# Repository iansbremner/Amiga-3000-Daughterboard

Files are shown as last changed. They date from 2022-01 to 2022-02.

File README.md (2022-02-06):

# Amiga-3000-Daughterboard
This is a recreation of the Rev 9 Daughterboard for the Amiga 3000
This is a 4 Layer board with signal on the upper and lower layers and a Power and Ground Plane.

When fabbing the board you will probably be asked if you want to remove the solder mask on the area for the Edge Connectors. It is fine to say Yes to this.

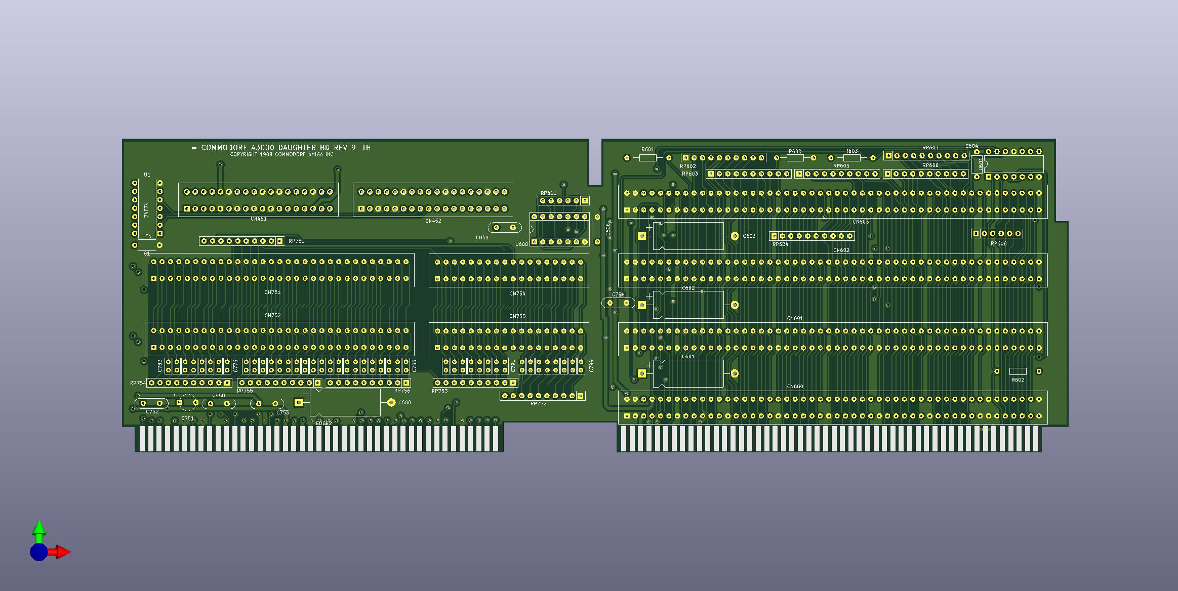
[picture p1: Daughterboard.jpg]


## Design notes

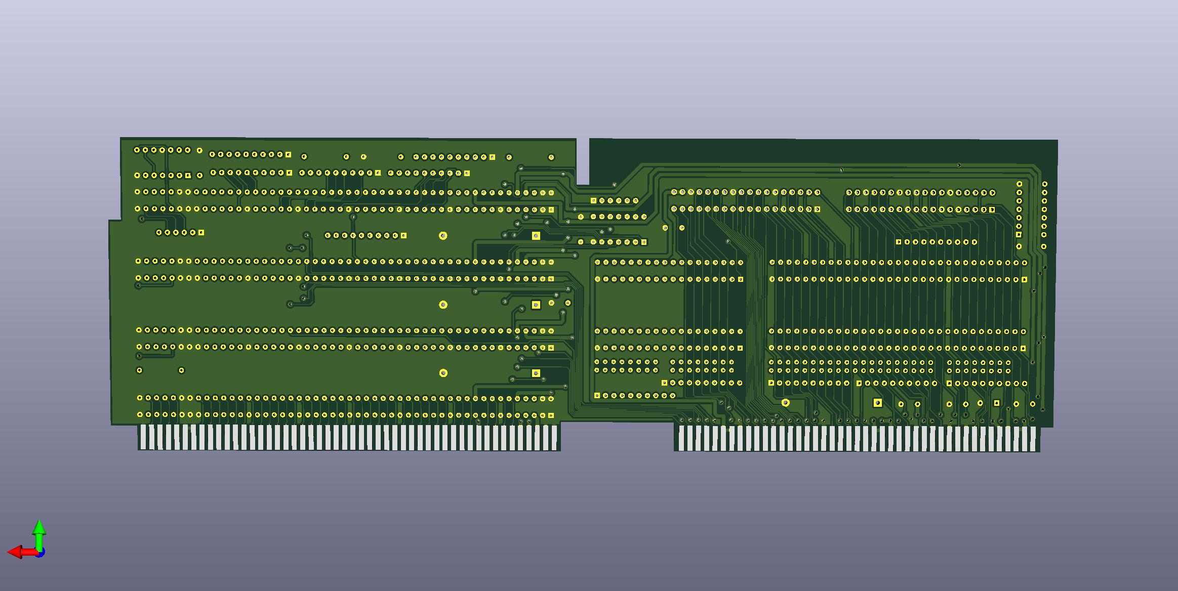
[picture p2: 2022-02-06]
Daughterboard_back.jpg

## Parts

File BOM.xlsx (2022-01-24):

Id | Designator | Package | Quantity | Designation | Part Number | URL | Unit Price | Total Cost
1 | CN752,CN751 | Standard Card Edge Connectors 100 VRT 062DP | 2 | ISA 8 Bit Connector | 6-5530843-5 | https://www.mouser.co.uk/ProductDetail/TE-Connectivity/6-5530843-5?qs=X1mjqRbeMc4evMKvgkFEjA%3D%3D | £3.18 | £6.36
2 | C751 | CP_Radial_D8.0mm_P5.00mm | 1 | 22uF 16V | ECA-1CEN220 | https://www.mouser.co.uk/ProductDetail/Panasonic/ECA-1CEN220 | £0.27 | £0.27
3 | CN755,CN754 | Standard Card Edge Connectors 36 VRT 036DP | 2 | ISA 16 Bit Extended Connector | 2-5530843-7 | https://www.mouser.co.uk/ProductDetail/TE-Connectivity/2-5530843-7?qs=D%2FjeFm%2FW2iQ%2FxNvh55mqEQ%3D%3D | £2.14 | £4.28
4 | RP752,RP753,RP754,RP755,RP756 | R_Array_SIP10 | 5 | 1K | 4610M-101-102LF | https://www.mouser.co.uk/ProductDetail/Bourns/4610M-101-102LF?qs=1EuqX6V5ZrfAKLDENGAusw%3D%3D | £0.47 | £2.34
5 | C458,C752,C753,C754,C849 | C_Disc_D7.0mm_W2.5mm_P5.00mm | 5 | 0.22uF | A224K20X7RF5UAAP | https://www.mouser.co.uk/ProductDetail/Vishay-BC-Components/A224K20X7RF5UAAP?qs=DPoM0jnrROXGL5u3LT1z6Q%3D%3D | £0.42 | £2.10
6 | CN451,CN452 | Standard Card Edge Connectors 36 Position | 2 | Video Slot | 2-5530843-7 | https://www.mouser.co.uk/ProductDetail/TE-Connectivity/2-5530843-7?qs=D%2FjeFm%2FW2iQ%2FxNvh55mqEQ%3D%3D | £2.14 | £4.28
7 | CN602,CN603,CN601,CN600 | Standard Card Edge Connectors CONN SEC II 100POS 100C/L | 4 | Zorro-III | 2-5530843-2 | https://www.mouser.co.uk/ProductDetail/TE-Connectivity-AMP/2-5530843-2 | £6.41 | £25.64
8 | R601,R603 | Resistor | 2 | 470 | SFR2500004700JA500 | https://www.mouser.co.uk/ProductDetail/Vishay-BC-Components/SFR2500004700JA500 | £0.10 | £0.20
9 | C602,C603,C601,C600 | CP_Axial_L21.0mm_D8.0mm_P28.00mm_Horizontal | 4 | 220uF 16V | MAL203135221E3 | https://www.mouser.co.uk/ProductDetail/Vishay-BC-Components/MAL203135221E3?qs=4T%252B5yYZyZYdCTfsAS92uLQ%3D%3D | £1.48 | £5.92
10 | R602,R600 | Resistor | 2 | 1K | MRS16000C1001FC100 | https://www.mouser.co.uk/ProductDetail/Vishay-BC-Components/MRS16000C1001FC100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 | £0.25 | £0.50
12 | U1,U601U600 | DIP-14_W7.62mm_Socket | 3 | DIP Socket | 110-43-314-41-001000 | https://www.mouser.co.uk/ProductDetail/Mill-Max/110-43-314-41-001000?qs=YW4OkVwgsvIOJfZQG89gzQ%3D%3D | £1.11 | £3.33
13 | C784,C785,C788,C786,C787,C789,C790,C793,C794,C792,C795,C756,C757,C758,C759,C760,C761,C762,C763,C764,C765,C766,C767,C768,C769,C770,C771,C772,C773,C774,C775,C776,C777,C778,C779,C780,C781,C782,C783,C791,C796,C797,C798,C799 | C_Rect_L4.6mm_W2.0mm_P2.50mm_MKS02_FKP02 | 44 | 1000pF | A102K15X7RF5UAAP | https://www.mouser.co.uk/ProductDetail/Vishay-BC-Components/A102K15X7RF5UAAP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 | £0.26 | £11.44
15 | RP608 | R_Array_SIP6 | 1 | 220/330 | 4606X-104-221/331L | https://www.mouser.co.uk/ProductDetail/Bourns/4606X-104-221-331L?qs=LaphGdK53R62nJP%252Bgwdp0w%3D%3D | £0.57 | £0.57
16 | RP603,RP602,RP604,RP605,RP606,RP607 | R_Array_SIP10 | 6 | 220/330 | 4610X-104-221/331LF | https://www.mouser.co.uk/ProductDetail/Bourns/4606X-104-221-331L?qs=LaphGdK53R62nJP%252Bgwdp0w%3D%3D | £0.51 | £3.04
18 | C1,C604,C606 | C_Axial_L5.1mm_D3.1mm_P7.50mm_Horizontal | 3 | 0.1uF | A104K15X7RH5UAAP |  | £0.42 | £1.26
19 | RP611 | R_Array_SIP6 | 1 | 1K | 4606M-101-102LF | https://www.mouser.co.uk/ProductDetail/Bourns/4606M-101-102LF?qs=5DXzRwmrLHFQqRAYa1Gabg%3D%3D | £0.51 | £0.51
20 | RP751 | R_Array_SIP10 | 1 | 4.7k | 4610H-101-472LF | https://www.mouser.co.uk/ProductDetail/Bourns/4610H-101-472LF?qs=QW4jRO6c0NMeQaO%252BEgHUiw%3D%3D | £0.55 | £0.55
21 | U600 | DIP-14_W7.62mm | 1 | 74HCT32 | CD74HCT32EE4 | https://www.mouser.co.uk/ProductDetail/Texas-Instruments/CD74HCT32EE4?qs=xFfolx0DHx2nbN4wbr6qGA%3D%3D | £0.56 | £0.56
22 | U601 | DIP-14_W7.62mm | 1 | 7407 | SN7407N | https://www.mouser.co.uk/ProductDetail/Texas-Instruments/SN7407N?qs=sGAEpiMZZMv0NwlthflBi6R2CPM2cSOQ | £0.91 | £0.91
23 | U1 | DIP-14_W7.62mm | 1 | 74F74 | SN74F74N | https://www.mouser.co.uk/ProductDetail/Texas-Instruments/SN74F74N?qs=AMJt07B76usrBxFudkVwtw%3D%3D | £0.51 | £0.51
 |  |  |  |  |  |  |  | £74.58

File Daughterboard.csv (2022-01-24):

Id | Designator | Package | Quantity | Designation | Supplier and ref
1 | CN752,CN751 | ISA 8 Bit | 2 | ISA_8_Bit
2 | C751 | CP_Radial_D8.0mm_P5.00mm | 1 | 22uF 16V
3 | CN755,CN754 | ISA 16 Bit | 2 | ISA_16_Bit_Extended
4 | RP752,RP753,RP754,RP755,RP756 | R_Array_SIP10 | 5 | 1K
5 | C458,C752,C753,C754,C849 | C_Disc_D7.0mm_W2.5mm_P5.00mm | 5 | 0.22uF
6 | CN451,CN452 | Video Slot | 2 | Video_Slot
7 | CN602,CN603,CN601,CN600 | Zorro-III | 4 | Zorro-III
8 | R601,R603 | Resistor | 2 | 470
9 | C602,C603,C601,C600 | CP_Axial_L21.0mm_D8.0mm_P28.00mm_Horizontal | 4 | 220uF 16V
10 | R602,R600 | Resistor | 2 | 1K
11 | EDGE1 | Edge2 | 1 | Edge1
12 | U600 | DIP-14_W7.62mm_Socket | 1 | 74HCT32
13 | C784,C785,C788,C786,C787,C789,C790,C793,C794,C792,C795,C756,C757,C758,C759,C760,C761,C762,C763,C764,C765,C766,C767,C768,C769,C770,C771,C772,C773,C774,C775,C776,C777,C778,C779,C780,C781,C782,C783,C791,C796,C797,C798,C799 | C_Rect_L4.6mm_W2.0mm_P2.50mm_MKS02_FKP02 | 44 | 1000pF
14 | U601 | DIP-14_W7.62mm | 1 | 7407
15 | RP608 | R_Array_SIP6 | 1 | 220/330
16 | RP603,RP602,RP604,RP605,RP606,RP607 | R_Array_SIP10 | 6 | 220/330
17 | EDGE2 | Edge1 | 1 | Edge2
18 | C1,C604,C606 | C_Axial_L5.1mm_D3.1mm_P7.50mm_Horizontal | 3 | 0.1uF
19 | RP611 | R_Array_SIP6 | 1 | 1K
20 | RP751 | R_Array_SIP10 | 1 | 4.7k
21 | U1 | DIP-14_W7.62mm | 1 | 74F74

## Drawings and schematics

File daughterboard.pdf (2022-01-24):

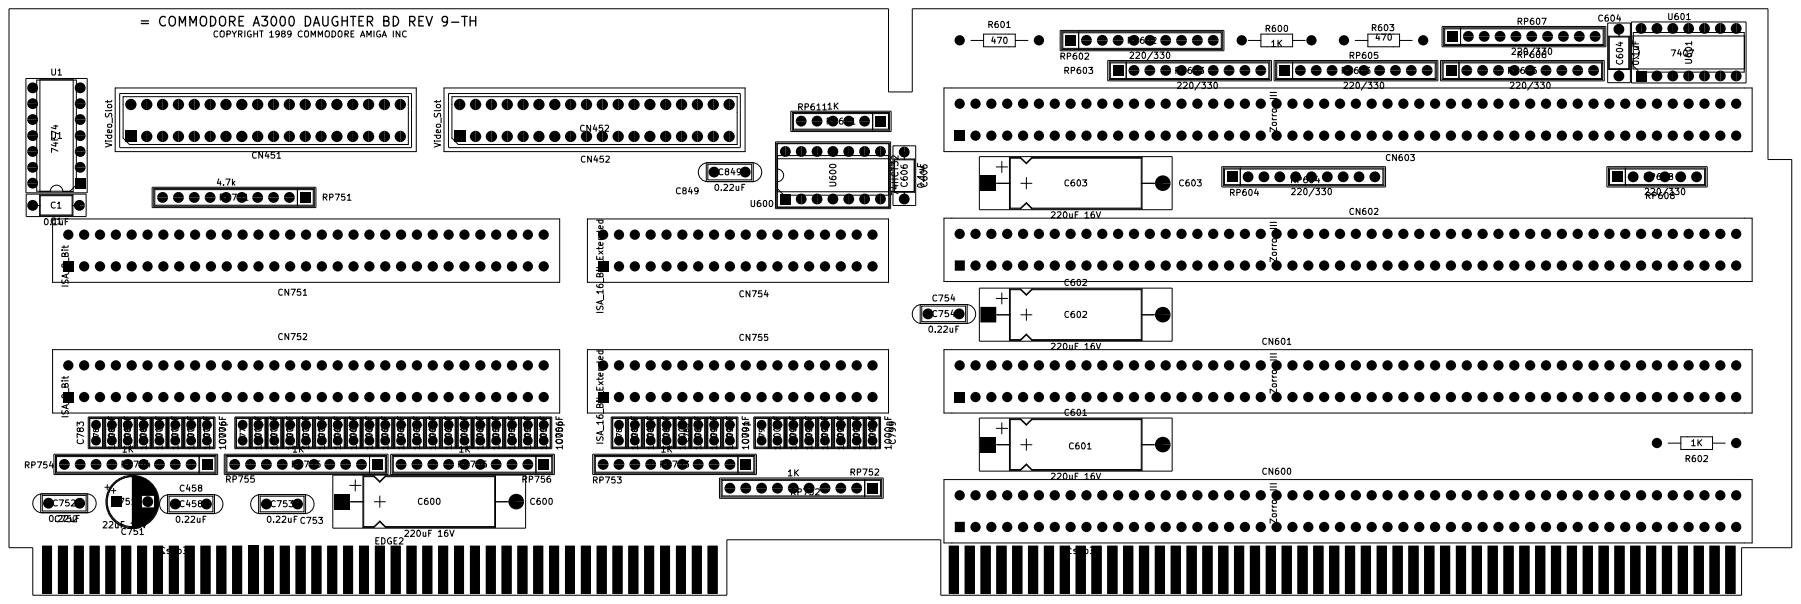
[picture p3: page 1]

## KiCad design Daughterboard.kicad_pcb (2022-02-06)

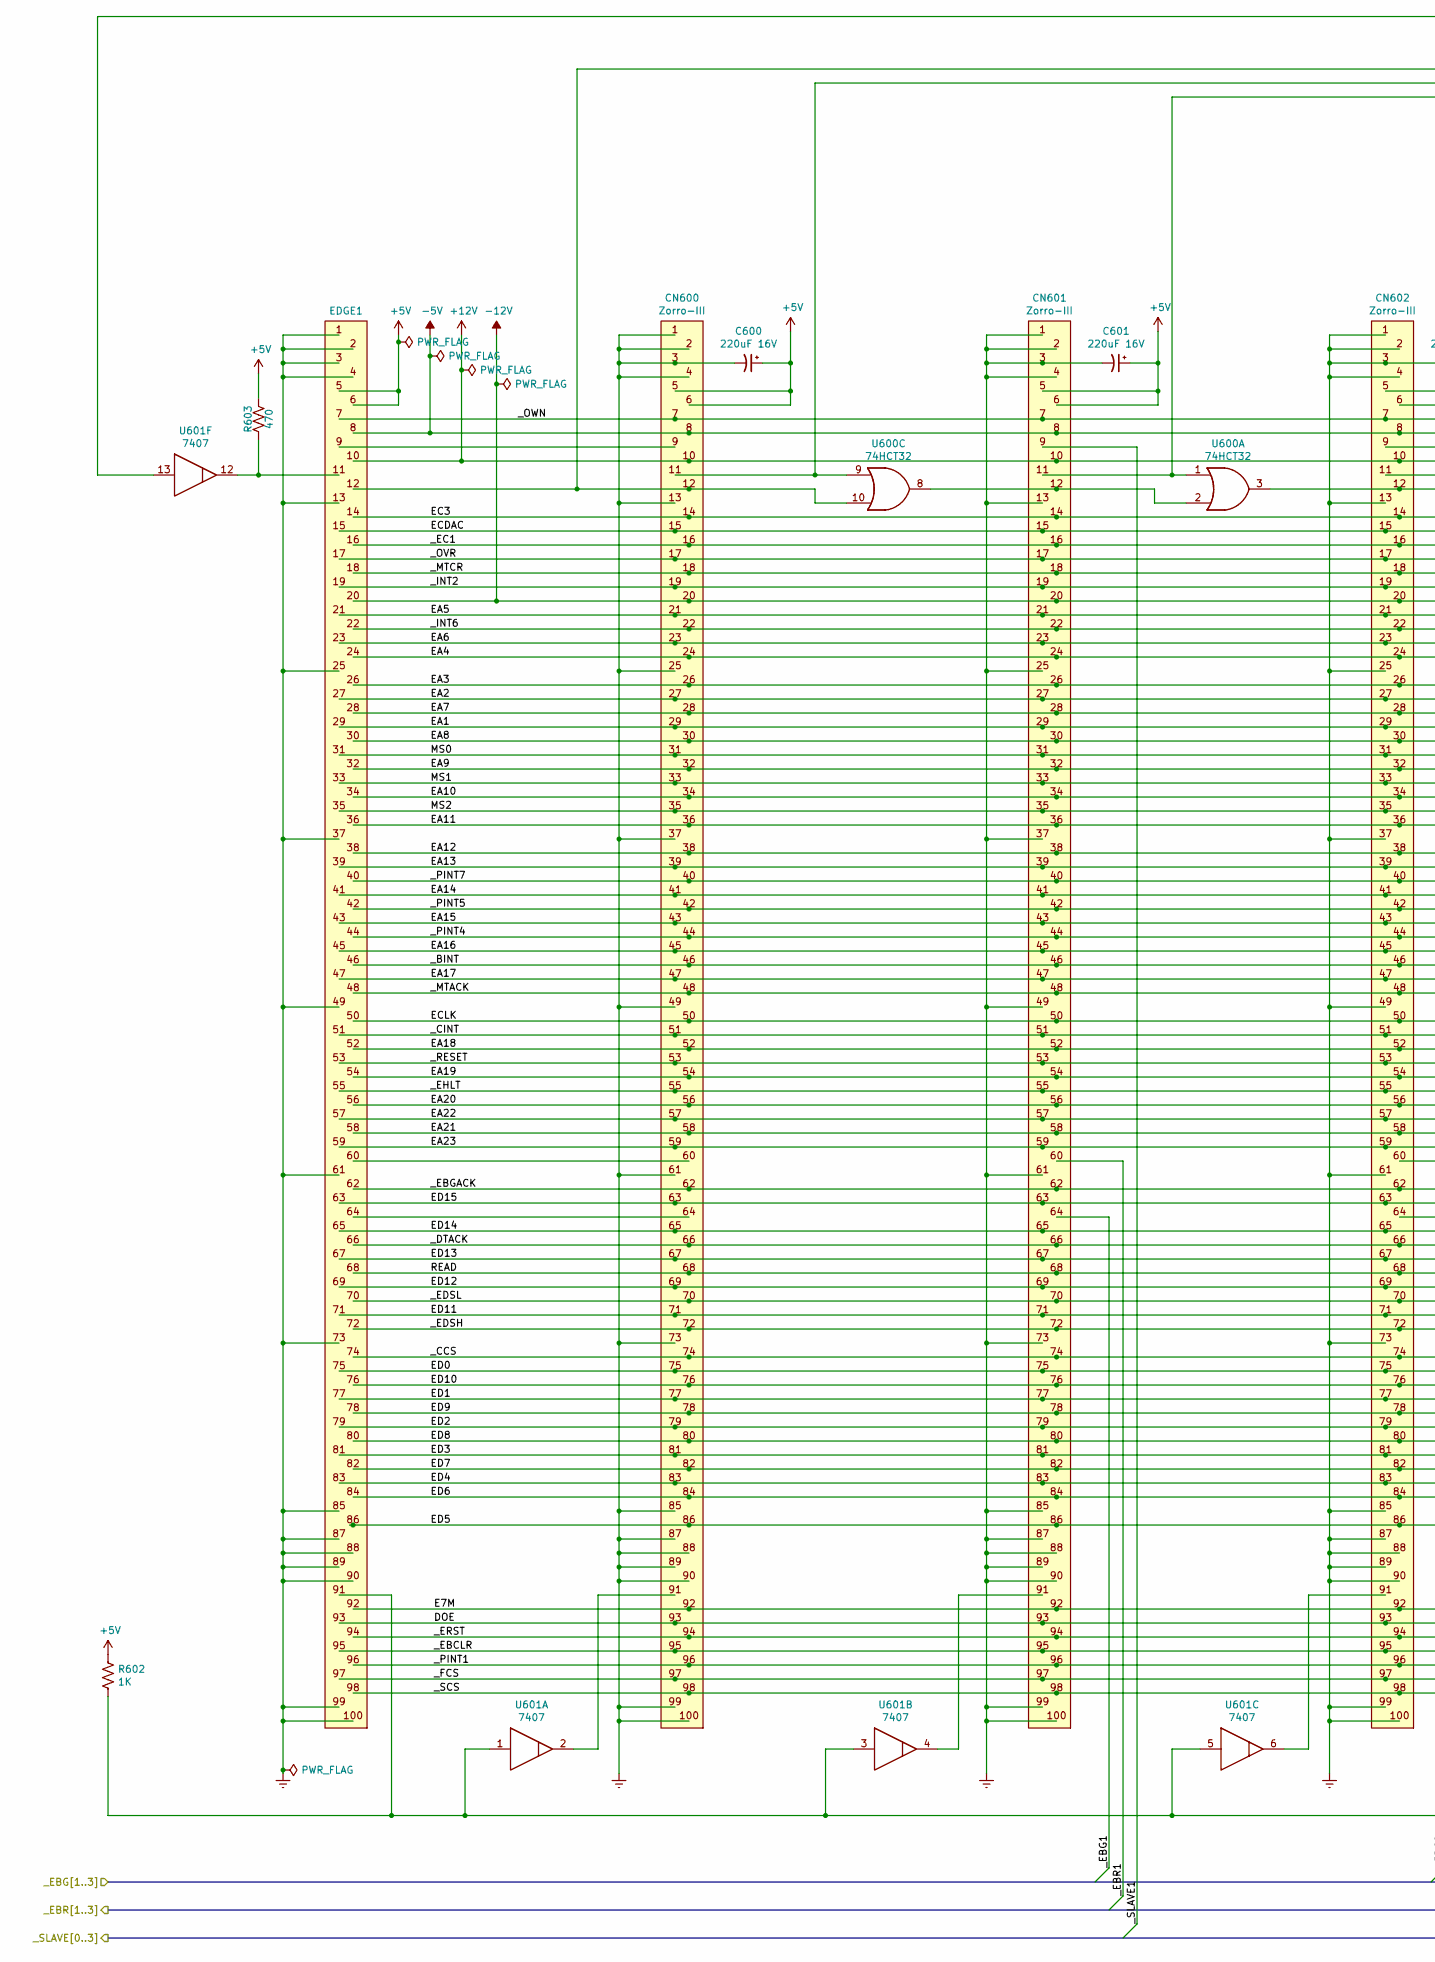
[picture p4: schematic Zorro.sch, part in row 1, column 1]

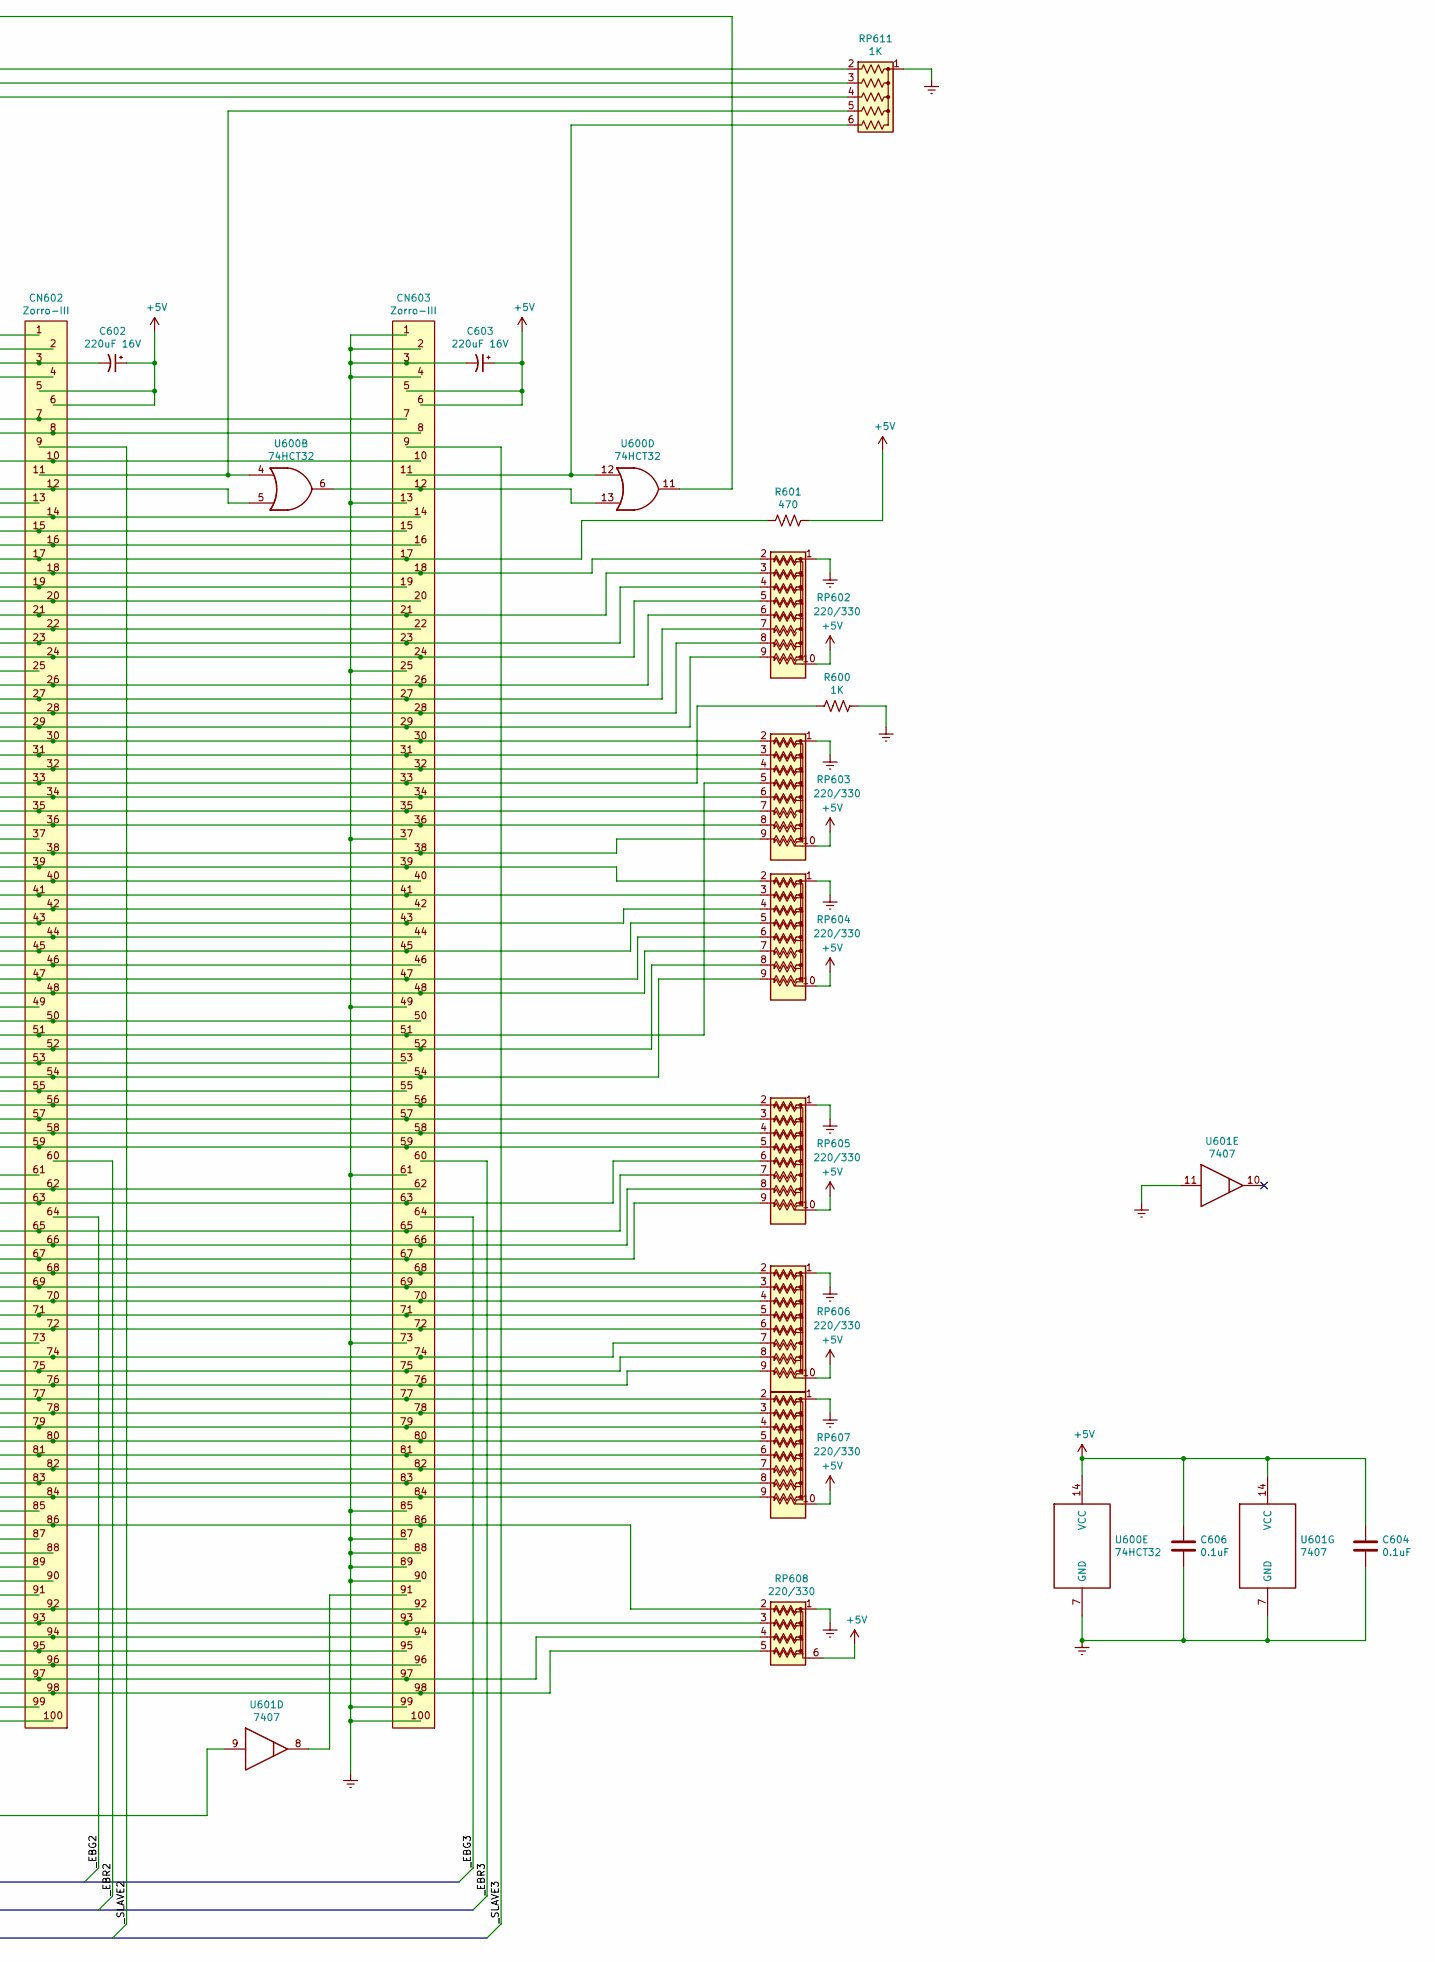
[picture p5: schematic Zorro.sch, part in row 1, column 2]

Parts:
C600, C601, C602, C603: 220uF 16V; CP_Axial_L21.0mm_D8.0mm_P28.00mm_Horizontal
C604, C606: 0.1uF; C_Axial_L5.1mm_D3.1mm_P7.50mm_Horizontal
CN600, CN601, CN602, CN603: Zorro-III
EDGE1: Edge1; Edge2
R600, R602: 1K; Resistor
R601, R603: 470; Resistor
RP602, RP603, RP604, RP605, RP606, RP607: 220/330; R_Array_SIP10
RP608: 220/330; R_Array_SIP6
RP611: 1K; R_Array_SIP6
U600: 74HCT32; DIP-14_W7.62mm_Socket
U601: 7407; DIP-14_W7.62mm

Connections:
+5V: C600.1, C601.1, C602.1, C603.1, C604.1, C606.1, CN600.5, CN600.6, CN601.5, CN601.6, CN602.5, CN602.6, CN603.5, CN603.6, EDGE1.5, EDGE1.6, R601.1, R602.1, R603.1, RP602.10 (R7), RP603.10 (R7), RP604.10 (R7), RP605.10 (R7), RP606.10 (R7), RP607.10 (R7), RP608.6 (R7), U600.14 (VCC), U601.14 (VCC); also elsewhere on the board
+12V: CN600.10, CN601.10, CN602.10, CN603.10, EDGE1.10; also elsewhere on the board
-5V: CN600.8, CN601.8, CN602.8, CN603.8, EDGE1.8; also elsewhere on the board
-12V: CN600.20, CN601.20, CN602.20, CN603.20, EDGE1.20; also elsewhere on the board
/Video & ISA/_EBG1: CN601.64; also elsewhere on the board
/Video & ISA/_EBG2: CN602.64; also elsewhere on the board
/Video & ISA/_EBG3: CN603.64; also elsewhere on the board
/Video & ISA/_EBR1: CN601.60; also elsewhere on the board
/Video & ISA/_EBR2: CN602.60; also elsewhere on the board
/Video & ISA/_EBR3: CN603.60; also elsewhere on the board
/Video & ISA/_SLAVE1: CN601.9; also elsewhere on the board
/Video & ISA/_SLAVE2: CN602.9; also elsewhere on the board
/Video & ISA/_SLAVE3: CN603.9; also elsewhere on the board
/Zorro/DOE: CN600.93, CN601.93, CN602.93, CN603.93, EDGE1.93, RP608.3 (R2)
/Zorro/E7M: CN600.92, CN601.92, CN602.92, CN603.92, EDGE1.92
/Zorro/EA1: CN600.29, CN601.29, CN602.29, CN603.29, EDGE1.29, RP602.9 (R6)
/Zorro/EA2: CN600.27, CN601.27, CN602.27, CN603.27, EDGE1.27, RP602.7 (R6)
/Zorro/EA3: CN600.26, CN601.26, CN602.26, CN603.26, EDGE1.26, RP602.6 (R5)
/Zorro/EA4: CN600.24, CN601.24, CN602.24, CN603.24, EDGE1.24, RP602.5 (R4)
/Zorro/EA5: CN600.21, CN601.21, CN602.21, CN603.21, EDGE1.21, RP602.3 (R2)
/Zorro/EA6: CN600.23, CN601.23, CN602.23, CN603.23, EDGE1.23, RP602.4 (R3)
/Zorro/EA7: CN600.28, CN601.28, CN602.28, CN603.28, EDGE1.28, RP602.8 (R6)
/Zorro/EA8: CN600.30, CN601.30, CN602.30, CN603.30, EDGE1.30, RP603.2 (R1)
/Zorro/EA9: CN600.32, CN601.32, CN602.32, CN603.32, EDGE1.32, RP603.4 (R3)
/Zorro/EA10: CN600.34, CN601.34, CN602.34, CN603.34, EDGE1.34, RP603.6 (R5)
/Zorro/EA11: CN600.36, CN601.36, CN602.36, CN603.36, EDGE1.36, RP603.8 (R6)
/Zorro/EA12: CN600.38, CN601.38, CN602.38, CN603.38, EDGE1.38, RP603.9 (R6)
/Zorro/EA13: CN600.39, CN601.39, CN602.39, CN603.39, EDGE1.39, RP604.2 (R1)
/Zorro/EA14: CN600.41, CN601.41, CN602.41, CN603.41, EDGE1.41, RP604.3 (R2)
/Zorro/EA15: CN600.43, CN601.43, CN602.43, CN603.43, EDGE1.43, RP604.4 (R3)
/Zorro/EA16: CN600.45, CN601.45, CN602.45, CN603.45, EDGE1.45, RP604.5 (R4)
/Zorro/EA17: CN600.47, CN601.47, CN602.47, CN603.47, EDGE1.47, RP604.6 (R5)
/Zorro/EA18: CN600.52, CN601.52, CN602.52, CN603.52, EDGE1.52, RP604.8 (R6)
/Zorro/EA19: CN600.54, CN601.54, CN602.54, CN603.54, EDGE1.54, RP604.9 (R6)
/Zorro/EA20: CN600.56, CN601.56, CN602.56, CN603.56, EDGE1.56, RP605.2 (R1)
/Zorro/EA21: CN600.58, CN601.58, CN602.58, CN603.58, EDGE1.58, RP605.4 (R3)
/Zorro/EA22: CN600.57, CN601.57, CN602.57, CN603.57, EDGE1.57, RP605.3 (R2)
/Zorro/EA23: CN600.59, CN601.59, CN602.59, CN603.59, EDGE1.59, RP605.5 (R4)
/Zorro/EC3: CN600.14, CN601.14, CN602.14, CN603.14, EDGE1.14
/Zorro/ECDAC: CN600.15, CN601.15, CN602.15, CN603.15, EDGE1.15
/Zorro/ECLK: CN600.50, CN601.50, CN602.50, CN603.50, EDGE1.50
/Zorro/ED0: CN600.75, CN601.75, CN602.75, CN603.75, EDGE1.75, RP606.8 (R6)
/Zorro/ED1: CN600.77, CN601.77, CN602.77, CN603.77, EDGE1.77, RP607.2 (R1)
/Zorro/ED2: CN600.79, CN601.79, CN602.79, CN603.79, EDGE1.79, RP607.4 (R3)
/Zorro/ED3: CN600.81, CN601.81, CN602.81, CN603.81, EDGE1.81, RP607.6 (R5)
/Zorro/ED4: CN600.83, CN601.83, CN602.83, CN603.83, EDGE1.83, RP607.8 (R6)
/Zorro/ED5: CN600.86, CN601.86, CN602.86, CN603.86, EDGE1.86, RP608.2 (R1)
/Zorro/ED6: CN600.84, CN601.84, CN602.84, CN603.84, EDGE1.84, RP607.9 (R6)
/Zorro/ED7: CN600.82, CN601.82, CN602.82, CN603.82, EDGE1.82, RP607.7 (R6)
/Zorro/ED8: CN600.80, CN601.80, CN602.80, CN603.80, EDGE1.80, RP607.5 (R4)
/Zorro/ED9: CN600.78, CN601.78, CN602.78, CN603.78, EDGE1.78, RP607.3 (R2)
/Zorro/ED10: CN600.76, CN601.76, CN602.76, CN603.76, EDGE1.76, RP606.9 (R6)
/Zorro/ED11: CN600.71, CN601.71, CN602.71, CN603.71, EDGE1.71, RP606.5 (R4)
/Zorro/ED12: CN600.69, CN601.69, CN602.69, CN603.69, EDGE1.69, RP606.3 (R2)
/Zorro/ED13: CN600.67, CN601.67, CN602.67, CN603.67, EDGE1.67, RP605.9 (R6)
/Zorro/ED14: CN600.65, CN601.65, CN602.65, CN603.65, EDGE1.65, RP605.7 (R6)
/Zorro/ED15: CN600.63, CN601.63, CN602.63, CN603.63, EDGE1.63, RP605.6 (R5)
/Zorro/MS0: CN600.31, CN601.31, CN602.31, CN603.31, EDGE1.31, RP603.3 (R2)
/Zorro/MS1: CN600.33, CN601.33, CN602.33, CN603.33, EDGE1.33, R600.2
/Zorro/MS2: CN600.35, CN601.35, CN602.35, CN603.35, EDGE1.35, RP603.7 (R6)
/Zorro/READ: CN600.68, CN601.68, CN602.68, CN603.68, EDGE1.68, RP606.2 (R1)
/Zorro/_BINT: CN600.46, CN601.46, CN602.46, CN603.46, EDGE1.46
/Zorro/_CCS: CN600.74, CN601.74, CN602.74, CN603.74, EDGE1.74, RP606.7 (R6)
/Zorro/_CINT: CN600.51, CN601.51, CN602.51, CN603.51, EDGE1.51, RP603.5 (R4)
/Zorro/_DTACK: CN600.66, CN601.66, CN602.66, CN603.66, EDGE1.66, RP605.8 (R6)
/Zorro/_EBCLR: CN600.95, CN601.95, CN602.95, CN603.95, EDGE1.95
/Zorro/_EBGACK: CN600.62, CN601.62, CN602.62, CN603.62, EDGE1.62
/Zorro/_EC1: CN600.16, CN601.16, CN602.16, CN603.16, EDGE1.16
/Zorro/_EDSH: CN600.72, CN601.72, CN602.72, CN603.72, EDGE1.72, RP606.6 (R5)
/Zorro/_EDSL: CN600.70, CN601.70, CN602.70, CN603.70, EDGE1.70, RP606.4 (R3)
/Zorro/_EHLT: CN600.55, CN601.55, CN602.55, CN603.55, EDGE1.55
/Zorro/_ERST: CN600.94, CN601.94, CN602.94, CN603.94, EDGE1.94
/Zorro/_FCS: CN600.97, CN601.97, CN602.97, CN603.97, EDGE1.97, RP608.4 (R3)
/Zorro/_INT2: CN600.19, CN601.19, CN602.19, CN603.19, EDGE1.19
/Zorro/_INT6: CN600.22, CN601.22, CN602.22, CN603.22, EDGE1.22
/Zorro/_MTACK: CN600.48, CN601.48, CN602.48, CN603.48, EDGE1.48, RP604.7 (R6)
/Zorro/_MTCR: CN600.18, CN601.18, CN602.18, CN603.18, EDGE1.18, RP602.2 (R1)
/Zorro/_OVR: CN600.17, CN601.17, CN602.17, CN603.17, EDGE1.17, R601.2
/Zorro/_OWN: CN600.7, CN601.7, CN602.7, CN603.7, EDGE1.7
/Zorro/_PINT1: CN600.96, CN601.96, CN602.96, CN603.96, EDGE1.96
/Zorro/_PINT4: CN600.44, CN601.44, CN602.44, CN603.44, EDGE1.44
/Zorro/_PINT5: CN600.42, CN601.42, CN602.42, CN603.42, EDGE1.42
/Zorro/_PINT7: CN600.40, CN601.40, CN602.40, CN603.40, EDGE1.40
/Zorro/_RESET: CN600.53, CN601.53, CN602.53, CN603.53, EDGE1.53
/Zorro/_SCS: CN600.98, CN601.98, CN602.98, CN603.98, EDGE1.98, RP608.5 (R4)
Earth: C600.2, C601.2, C602.2, C603.2, C604.2, C606.2, CN600.1, CN600.2, CN600.3, CN600.4, CN600.13, CN600.25, CN600.37, CN600.49, CN600.61, CN600.73, CN600.85, CN600.87, CN600.88, CN600.89, CN600.90, CN600.99, CN600.100, CN601.1, CN601.2, CN601.3, CN601.4, CN601.13, CN601.25, CN601.37, CN601.49, CN601.61, CN601.73, CN601.85, CN601.87, CN601.88, CN601.89, CN601.90, CN601.99, CN601.100, CN602.1, CN602.2, CN602.3, CN602.4, CN602.13, CN602.25, CN602.37, CN602.49, CN602.61, CN602.73, CN602.85, CN602.87, CN602.88, CN602.89, CN602.90, CN602.99, CN602.100, CN603.1, CN603.2, CN603.3, CN603.4, CN603.13, CN603.25, CN603.37, CN603.49, CN603.61, CN603.73, CN603.85, CN603.87, CN603.88, CN603.89, CN603.90, CN603.99, CN603.100, EDGE1.1, EDGE1.2, EDGE1.3, EDGE1.4, EDGE1.13, EDGE1.25, EDGE1.37, EDGE1.49, EDGE1.61, EDGE1.73, EDGE1.85, EDGE1.87, EDGE1.88, EDGE1.89, EDGE1.90, EDGE1.99, EDGE1.100, R600.1, RP602.1 (common), RP603.1 (common), RP604.1 (common), RP605.1 (common), RP606.1 (common), RP607.1 (common), RP608.1 (common), RP611.1 (common), U600.7 (GND), U601.7 (GND), U601.11; also elsewhere on the board
unnamed: CN600.9, EDGE1.9
unnamed: CN600.11, RP611.3 (R2), U600.9
unnamed: CN600.12, EDGE1.12, RP611.2 (R1), U600.10
unnamed: CN600.60, EDGE1.60
unnamed: CN600.64, EDGE1.64
unnamed: CN600.91, U601.2
unnamed: CN601.11, RP611.4 (R3), U600.1
unnamed: CN601.12, U600.2, U600.8
unnamed: CN601.91, U601.4
unnamed: CN602.11, RP611.5 (R4), U600.4
unnamed: CN602.12, U600.3, U600.5
unnamed: CN602.91, U601.6
unnamed: CN603.11, RP611.6 (R5), U600.12
unnamed: CN603.12, U600.6, U600.13
unnamed: CN603.91, U601.8
unnamed: EDGE1.11, R603.2, U601.12
unnamed: EDGE1.91, R602.2, U601.1, U601.3, U601.5, U601.9
unnamed: U600.11, U601.13

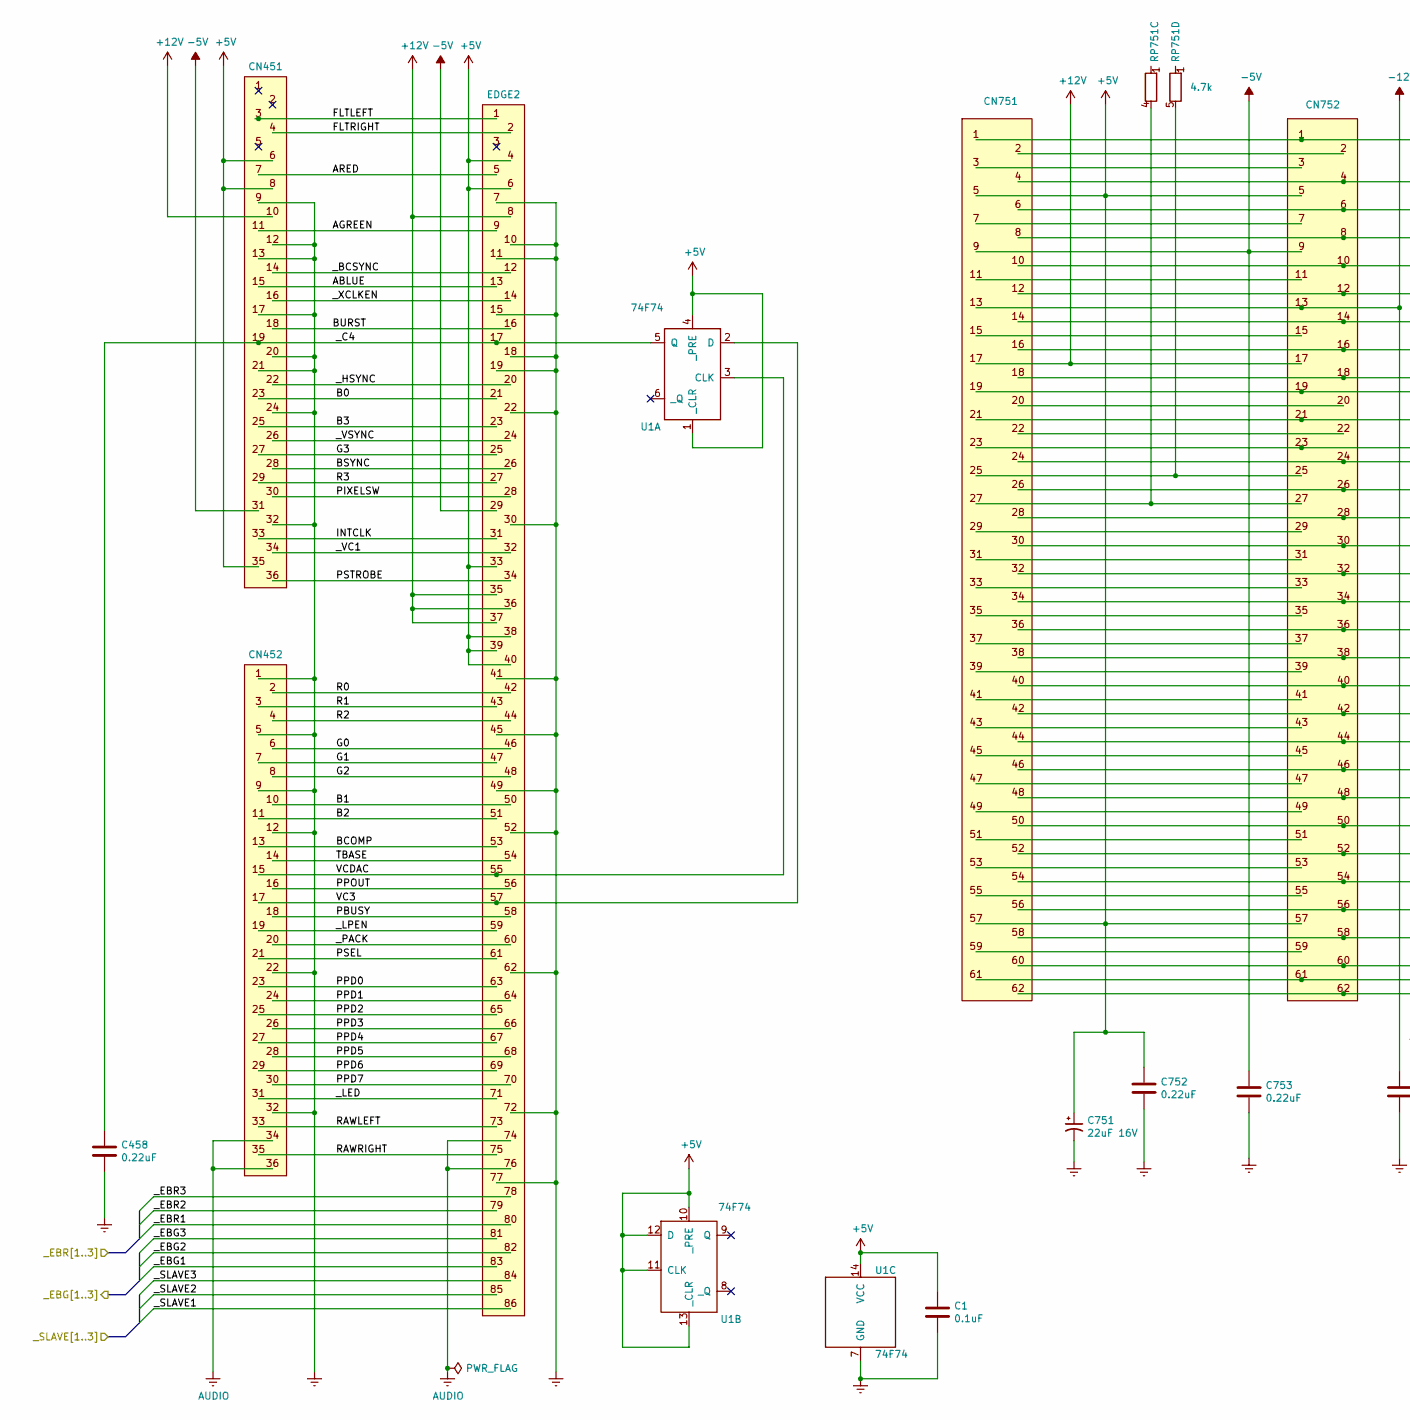
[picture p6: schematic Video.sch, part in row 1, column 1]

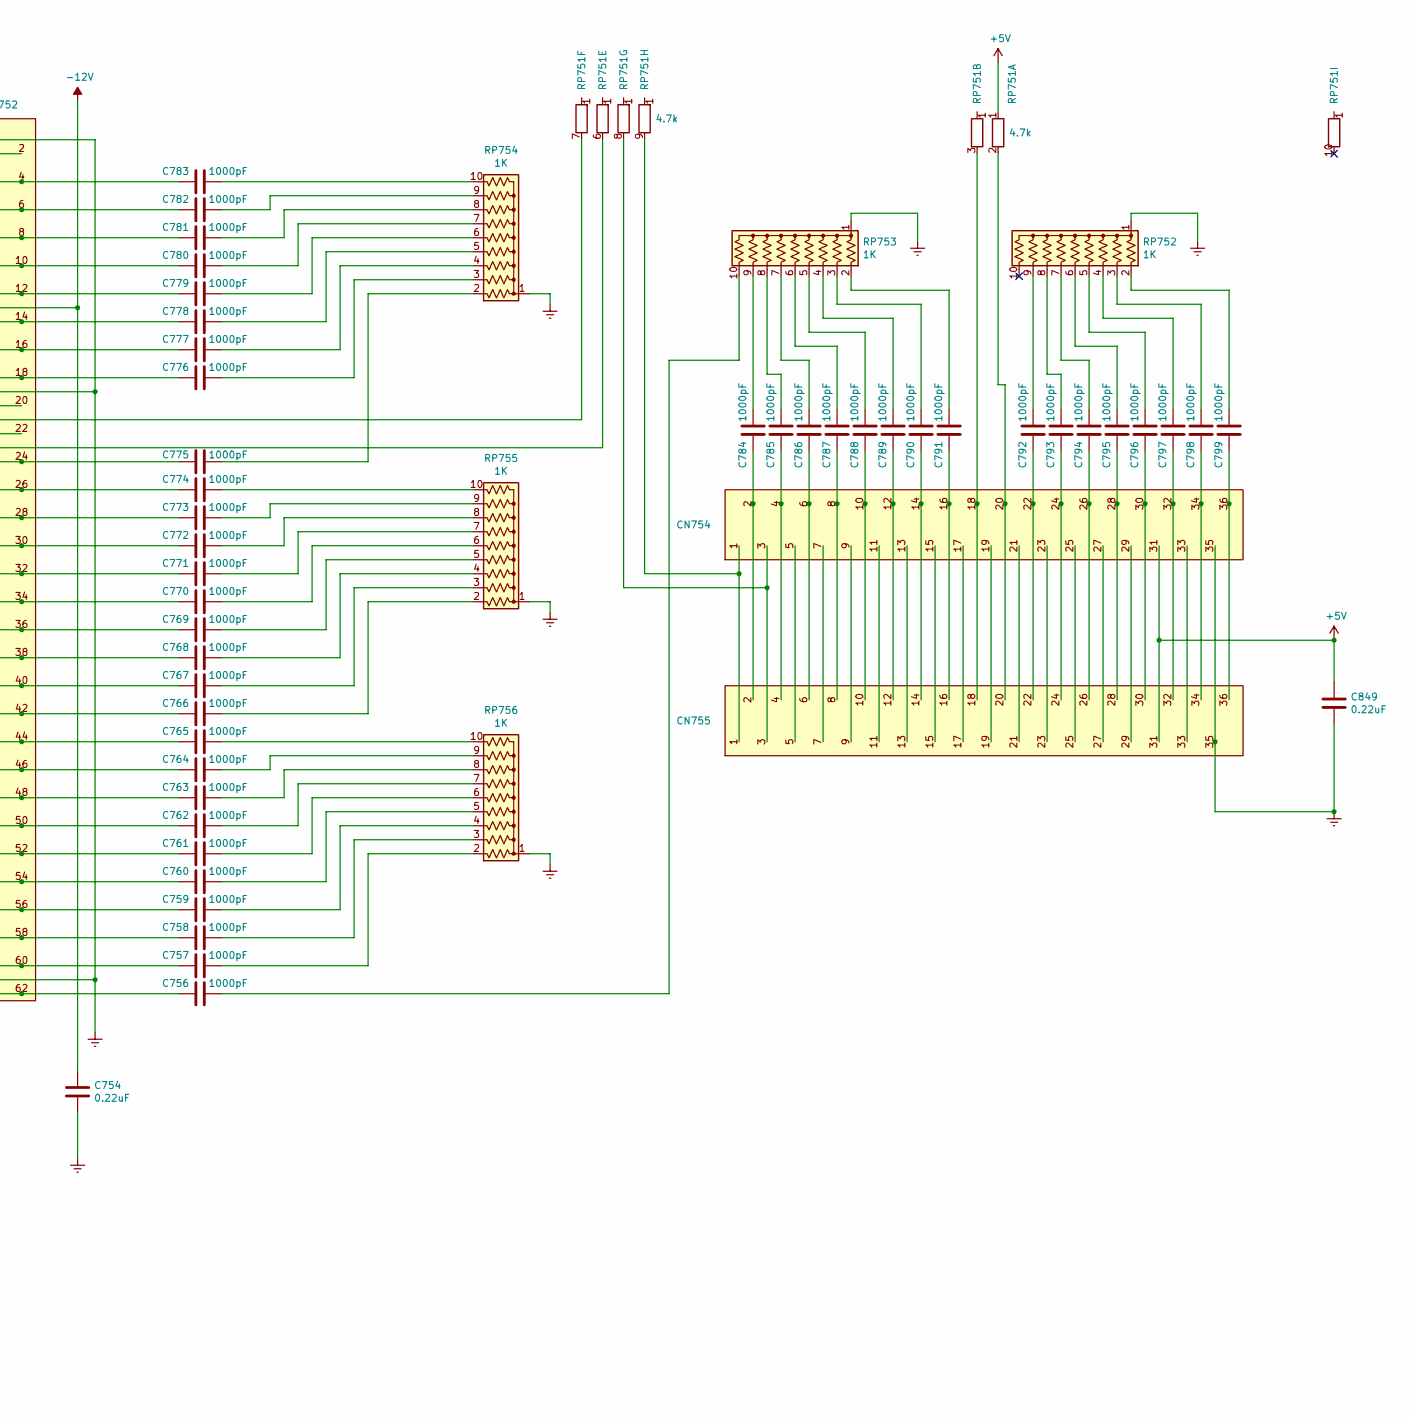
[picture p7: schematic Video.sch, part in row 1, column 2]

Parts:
C1: 0.1uF; C_Axial_L5.1mm_D3.1mm_P7.50mm_Horizontal
C458, C752, C753, C754, C849: 0.22uF; C_Disc_D7.0mm_W2.5mm_P5.00mm
C751: 22uF 16V; CP_Radial_D8.0mm_P5.00mm
C756, C757, C758, C759, C760, C761, C762, C763, C764, C765, C766, C767, C768, C769, C770, C771, C772, C773, C774, C775, C776, C777, C778, C779, C780, C781, C782, C783, C784, C785, C786, C787, C788, C789, C790, C791, C792, C793, C794, C795, C796, C797, C798, C799: 1000pF; C_Rect_L4.6mm_W2.0mm_P2.50mm_MKS02_FKP02
CN451, CN452: Video_Slot; Video Slot
CN751, CN752: ISA_8_Bit; ISA 8 Bit
CN754, CN755: ISA_16_Bit_Extended; ISA 16 Bit
EDGE2: Edge2; Edge1
RP751: 4.7k; R_Array_SIP10
RP752, RP753, RP754, RP755, RP756: 1K; R_Array_SIP10
U1: 74F74; DIP-14_W7.62mm

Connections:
+5V: C1.1, C751.1, C752.1, C849.1, CN451.6, CN451.8, CN451.35, CN751.5, CN751.57, CN752.5, CN752.57, CN754.31, CN755.31, EDGE2.4, EDGE2.6, EDGE2.33, EDGE2.38, EDGE2.39, EDGE2.40, RP751.1 (R1.1), U1.1 (_CLR), U1.4 (_PRE), U1.10 (_PRE), U1.11 (CLK), U1.12 (D), U1.13 (_CLR), U1.14 (VCC); also elsewhere on the board
+12V: CN451.10, CN751.17, CN752.17, EDGE2.8, EDGE2.35, EDGE2.36, EDGE2.37; also elsewhere on the board
-5V: C753.1, CN451.31, CN751.9, CN752.9, EDGE2.29; also elsewhere on the board
-12V: C754.1, CN751.13, CN752.13; also elsewhere on the board
/Video & ISA/ABLUE: CN451.15, EDGE2.13
/Video & ISA/AGREEN: CN451.11, EDGE2.9
/Video & ISA/ARED: CN451.7, EDGE2.5
/Video & ISA/B0: CN451.23, EDGE2.21
/Video & ISA/B1: CN452.10, EDGE2.50
/Video & ISA/B2: CN452.11, EDGE2.51
/Video & ISA/B3: CN451.25, EDGE2.23
/Video & ISA/BCOMP: CN452.13, EDGE2.53
/Video & ISA/BSYNC: CN451.28, EDGE2.26
/Video & ISA/BURST: CN451.18, EDGE2.16
/Video & ISA/FLTLEFT: CN451.3, EDGE2.1
/Video & ISA/FLTRIGHT: CN451.4, EDGE2.2
/Video & ISA/G0: CN452.6, EDGE2.46
/Video & ISA/G1: CN452.7, EDGE2.47
/Video & ISA/G2: CN452.8, EDGE2.48
/Video & ISA/G3: CN451.27, EDGE2.25
/Video & ISA/INTCLK: CN451.33, EDGE2.31
/Video & ISA/PBUSY: CN452.18, EDGE2.58
/Video & ISA/PIXELSW: CN451.30, EDGE2.28
/Video & ISA/PPD0: CN452.23, EDGE2.63
/Video & ISA/PPD1: CN452.24, EDGE2.64
/Video & ISA/PPD2: CN452.25, EDGE2.65
/Video & ISA/PPD3: CN452.26, EDGE2.66
/Video & ISA/PPD4: CN452.27, EDGE2.67
/Video & ISA/PPD5: CN452.28, EDGE2.68
/Video & ISA/PPD6: CN452.29, EDGE2.69
/Video & ISA/PPD7: CN452.30, EDGE2.70
/Video & ISA/PPOUT: CN452.16, EDGE2.56
/Video & ISA/PSEL: CN452.21, EDGE2.61
/Video & ISA/PSTROBE: CN451.36, EDGE2.34
/Video & ISA/R0: CN452.2, EDGE2.42
/Video & ISA/R1: CN452.3, EDGE2.43
/Video & ISA/R2: CN452.4, EDGE2.44
/Video & ISA/R3: CN451.29, EDGE2.27
/Video & ISA/RAWLEFT: CN452.33, EDGE2.73
/Video & ISA/RAWRIGHT: CN452.35, EDGE2.75
/Video & ISA/TBASE: CN452.14, EDGE2.54
/Video & ISA/VC3: CN452.17, EDGE2.57, U1.2 (D)
/Video & ISA/VCDAC: CN452.15, EDGE2.55, U1.3 (CLK)
/Video & ISA/_BCSYNC: CN451.14, EDGE2.12
/Video & ISA/_C4: C458.1, CN451.19, EDGE2.17, U1.5 (Q)
/Video & ISA/_EBG1: EDGE2.83; also elsewhere on the board
/Video & ISA/_EBG2: EDGE2.82; also elsewhere on the board
/Video & ISA/_EBG3: EDGE2.81; also elsewhere on the board
/Video & ISA/_EBR1: EDGE2.80; also elsewhere on the board
/Video & ISA/_EBR2: EDGE2.79; also elsewhere on the board
/Video & ISA/_EBR3: EDGE2.78; also elsewhere on the board
/Video & ISA/_HSYNC: CN451.22, EDGE2.20
/Video & ISA/_LED: CN452.31, EDGE2.71
/Video & ISA/_LPEN: CN452.19, EDGE2.59
/Video & ISA/_PACK: CN452.20, EDGE2.60
/Video & ISA/_SLAVE1: EDGE2.86; also elsewhere on the board
/Video & ISA/_SLAVE2: EDGE2.85; also elsewhere on the board
/Video & ISA/_SLAVE3: EDGE2.84; also elsewhere on the board
/Video & ISA/_VC1: CN451.34, EDGE2.32
/Video & ISA/_VSYNC: CN451.26, EDGE2.24
/Video & ISA/_XCLKEN: CN451.16, EDGE2.14
AUDIO: CN452.34, CN452.36, EDGE2.74, EDGE2.76
Earth: C1.2, C458.2, C751.2, C752.2, C753.2, C754.2, C849.2, CN451.9, CN451.12, CN451.13, CN451.17, CN451.20, CN451.21, CN451.24, CN451.32, CN452.1, CN452.5, CN452.9, CN452.12, CN452.22, CN452.32, CN751.1, CN751.19, CN751.61, CN752.1, CN752.19, CN752.61, CN754.35, CN755.35, EDGE2.7, EDGE2.10, EDGE2.11, EDGE2.15, EDGE2.18, EDGE2.19, EDGE2.22, EDGE2.30, EDGE2.41, EDGE2.45, EDGE2.49, EDGE2.52, EDGE2.62, EDGE2.72, EDGE2.77, RP752.1 (common), RP753.1 (common), RP754.1 (common), RP755.1 (common), RP756.1 (common), U1.7 (GND); also elsewhere on the board
unnamed: C756.1, RP753.10 (R9)
unnamed: C756.2, CN751.62, CN752.62
unnamed: C757.1, RP756.2 (R1)
unnamed: C757.2, CN751.60, CN752.60
unnamed: C758.1, RP756.3 (R2)
unnamed: C758.2, CN751.58, CN752.58
unnamed: C759.1, RP756.4 (R3)
unnamed: C759.2, CN751.56, CN752.56
unnamed: C760.1, RP756.5 (R4)
unnamed: C760.2, CN751.54, CN752.54
unnamed: C761.1, RP756.6 (R5)
unnamed: C761.2, CN751.52, CN752.52
unnamed: C762.1, RP756.7 (R6)
unnamed: C762.2, CN751.50, CN752.50
unnamed: C763.1, RP756.8 (R7)
unnamed: C763.2, CN751.48, CN752.48
unnamed: C764.1, RP756.9 (R8)
unnamed: C764.2, CN751.46, CN752.46
unnamed: C765.1, RP756.10 (R9)
unnamed: C765.2, CN751.44, CN752.44
unnamed: C766.1, RP755.2 (R1)
unnamed: C766.2, CN751.42, CN752.42
unnamed: C767.1, RP755.3 (R2)
unnamed: C767.2, CN751.40, CN752.40
unnamed: C768.1, RP755.4 (R3)
unnamed: C768.2, CN751.38, CN752.38
unnamed: C769.1, RP755.5 (R4)
unnamed: C769.2, CN751.36, CN752.36
unnamed: C770.1, RP755.6 (R5)
unnamed: C770.2, CN751.34, CN752.34
unnamed: C771.1, RP755.7 (R6)
unnamed: C771.2, CN751.32, CN752.32
unnamed: C772.1, RP755.8 (R7)
unnamed: C772.2, CN751.30, CN752.30
unnamed: C773.1, RP755.9 (R8)
unnamed: C773.2, CN751.28, CN752.28
unnamed: C774.1, RP755.10 (R9)
unnamed: C774.2, CN751.26, CN752.26
unnamed: C775.1, RP754.2 (R1)
unnamed: C775.2, CN751.24, CN752.24
unnamed: C776.1, RP754.3 (R2)
unnamed: C776.2, CN751.18, CN752.18
unnamed: C777.1, RP754.4 (R3)
unnamed: C777.2, CN751.16, CN752.16
unnamed: C778.1, RP754.5 (R4)
unnamed: C778.2, CN751.14, CN752.14
unnamed: C779.1, RP754.6 (R5)
unnamed: C779.2, CN751.12, CN752.12
unnamed: C780.1, RP754.7 (R6)
unnamed: C780.2, CN751.10, CN752.10
unnamed: C781.1, RP754.8 (R7)
unnamed: C781.2, CN751.8, CN752.8
unnamed: C782.1, RP754.9 (R8)
unnamed: C782.2, CN751.6, CN752.6
unnamed: C783.1, RP754.10 (R9)
unnamed: C783.2, CN751.4, CN752.4
unnamed: C784.1, RP753.9 (R8)
unnamed: C784.2, CN754.2, CN755.2
unnamed: C785.1, RP753.8 (R7)
unnamed: C785.2, CN754.4, CN755.4
unnamed: C786.1, RP753.7 (R6)
unnamed: C786.2, CN754.6, CN755.6
unnamed: C787.1, RP753.6 (R5)
unnamed: C787.2, CN754.8, CN755.8
unnamed: C788.1, RP753.5 (R4)
unnamed: C788.2, CN754.10, CN755.10
unnamed: C789.1, RP753.4 (R3)
unnamed: C789.2, CN754.12, CN755.12
unnamed: C790.1, RP753.3 (R2)
unnamed: C790.2, CN754.14, CN755.14
unnamed: C791.1, RP753.2 (R1)
unnamed: C791.2, CN754.16, CN755.16
unnamed: C792.1, RP752.9 (R8)
unnamed: C792.2, CN754.22, CN755.22
unnamed: C793.1, RP752.8 (R7)
unnamed: C793.2, CN754.24, CN755.24
unnamed: C794.1, RP752.7 (R6)
unnamed: C794.2, CN754.26, CN755.26
unnamed: C795.1, RP752.6 (R5)
unnamed: C795.2, CN754.28, CN755.28
unnamed: C796.1, RP752.5 (R4)
unnamed: C796.2, CN754.30, CN755.30
unnamed: C797.1, RP752.4 (R3)
unnamed: C797.2, CN754.32, CN755.32
unnamed: C798.1, RP752.3 (R2)
unnamed: C798.2, CN754.34, CN755.34
unnamed: C799.1, RP752.2 (R1)
unnamed: C799.2, CN754.36, CN755.36
unnamed: CN751.2, CN752.2
unnamed: CN751.3, CN752.3
unnamed: CN751.7, CN752.7
unnamed: CN751.11, CN752.11
unnamed: CN751.15, CN752.15
unnamed: CN751.20, CN752.20
unnamed: CN751.21, CN752.21, RP751.7 (R6.2)
unnamed: CN751.22, CN752.22
unnamed: CN751.23, CN752.23, RP751.6 (R5.2)
unnamed: CN751.25, CN752.25, RP751.5 (R4.2)
unnamed: CN751.27, CN752.27, RP751.4 (R3.2)
unnamed: CN751.29, CN752.29
unnamed: CN751.31, CN752.31
unnamed: CN751.33, CN752.33
unnamed: CN751.35, CN752.35
unnamed: CN751.37, CN752.37
unnamed: CN751.39, CN752.39
unnamed: CN751.41, CN752.41
unnamed: CN751.43, CN752.43
unnamed: CN751.45, CN752.45
unnamed: CN751.47, CN752.47
unnamed: CN751.49, CN752.49
unnamed: CN751.51, CN752.51
unnamed: CN751.53, CN752.53
unnamed: CN751.55, CN752.55
unnamed: CN751.59, CN752.59
unnamed: CN754.1, CN755.1, RP751.9 (R8.2)
unnamed: CN754.3, CN755.3, RP751.8 (R7.2)
unnamed: CN754.5, CN755.5
unnamed: CN754.7, CN755.7
unnamed: CN754.9, CN755.9
unnamed: CN754.11, CN755.11
unnamed: CN754.13, CN755.13
unnamed: CN754.15, CN755.15
unnamed: CN754.17, CN755.17
unnamed: CN754.18, CN755.18, RP751.3 (R2.2)
unnamed: CN754.19, CN755.19
unnamed: CN754.20, CN755.20, RP751.2 (R1.2)
unnamed: CN754.21, CN755.21
unnamed: CN754.23, CN755.23
unnamed: CN754.25, CN755.25
unnamed: CN754.27, CN755.27
unnamed: CN754.29, CN755.29
unnamed: CN754.33, CN755.33

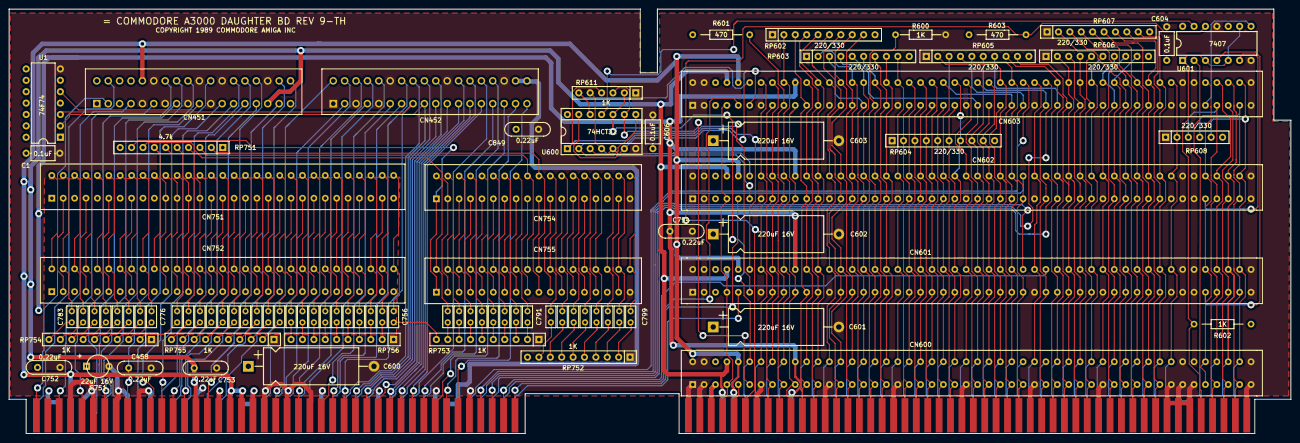
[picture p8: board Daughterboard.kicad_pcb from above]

Board: 4 copper layers, 285.8 x 94.6 mm, 90 parts (0 on the bottom side), 285 nets.

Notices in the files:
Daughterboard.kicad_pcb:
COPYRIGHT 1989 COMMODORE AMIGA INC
